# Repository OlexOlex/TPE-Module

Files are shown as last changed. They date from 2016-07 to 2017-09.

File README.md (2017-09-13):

# TPE-Module
**A simple, small, cheap and relatively easy to build module to control 3 PWM driven and 2 binary (on/off) outputs via WIFI and a webinterface** (designed for controlling 3 vibrators and 2 other custom modules, especially in BDSM plays, that's why there is a password protection available)

Runs on any newer ESP8266 module running NodeMCU (the ones with more RAM than the first version, usually featuring 4MB flash)<br/>
The integer version of NodeMCU is reccomended, the floatingpoint accurate version will most probably use too much RAM.

To flash NodeMCU to your module you can use programs like [esptool.py](https://github.com/themadinventor/esptool/blob/master/esptool.py)

To access the NodeMCU filesystem you can use programs like [ESPlorer](http://esp8266.ru/esplorer/)<br/>
You need it to upload the Lua server program, the two configuration files (ESPWIFI.conf and ESPWebserver.conf) and any sequence files. You also need it to test (execute) the Lua server program before renaming it so it gets executed automatically at startup (broken init.lua files might brick your module and force you to re-flash NodeMCU to un-brick it).

In case you change anything in the Lua server program, remember to compress the Lua program for uploading it using [Luasrcdiet](http://esp8266.ru/esplorer/) (otherwise it will most likely bust the modules RAM when executing).

Documentation is not finished by now, I hope this README, the comments, the images and 3D-drawings provided suffice. Browse the project, it consists of only a few files separated into a software and a hardware part.

The Module with an attached vibrating bullet can look like this:

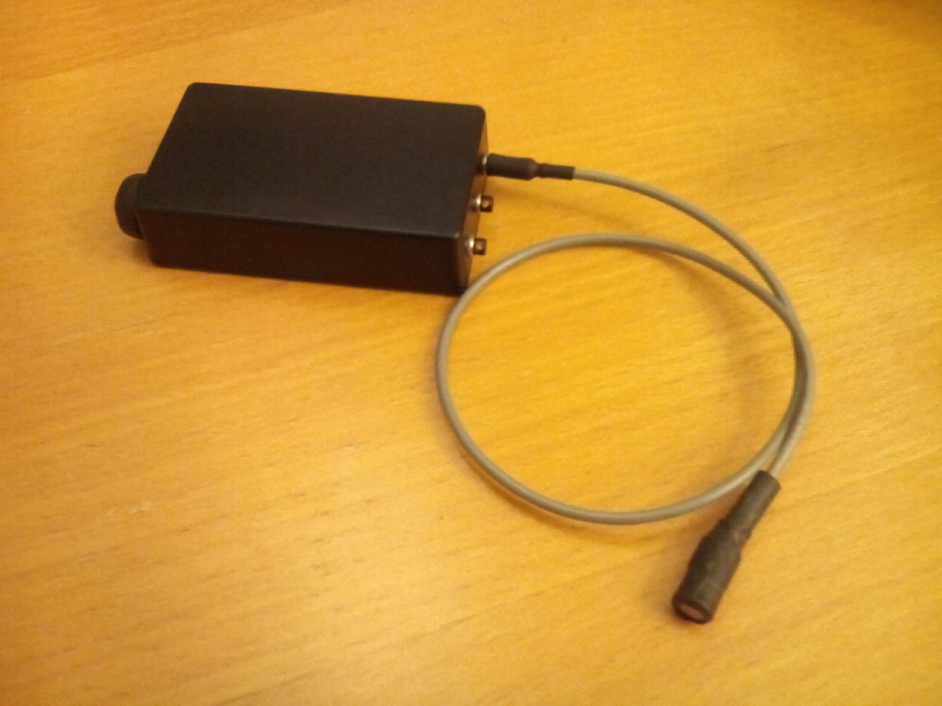
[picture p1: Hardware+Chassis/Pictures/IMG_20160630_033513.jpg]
Module photos


The website can look like this in english, there is an english and a german sample config file available<br/>
Enable or disable any outputs options to be displayed and name (mostly) anything as you wish.<br>
The "Unlock" and "Beep" are just an example, you need to attach a custom module to an output port in order to get any functionality from the two binary outputs. They turn "on" for 20ms  when activated.

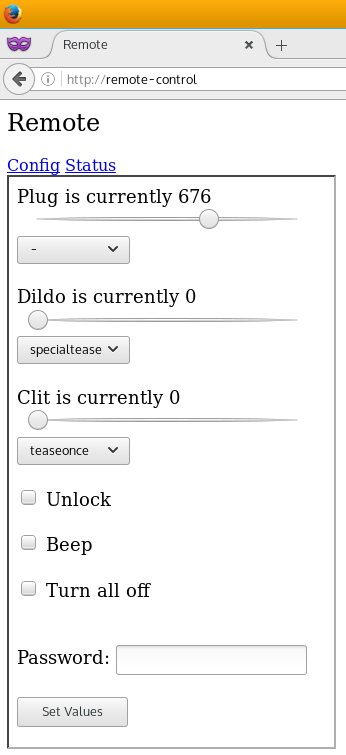
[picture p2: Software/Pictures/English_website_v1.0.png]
Main website screenshot
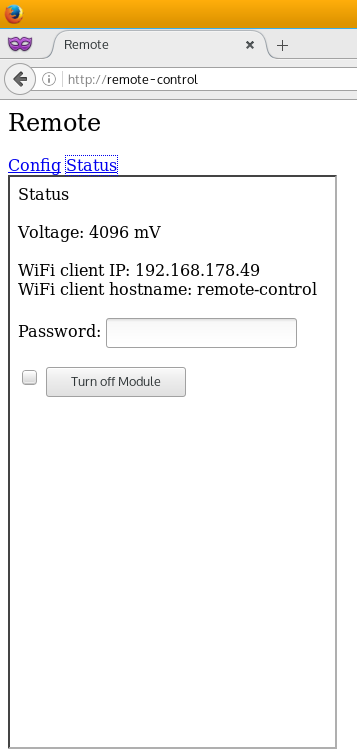
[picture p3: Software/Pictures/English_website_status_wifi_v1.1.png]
Status and turn-off website screenshot
 

## Features:
* Provides a **WIFI-accesspoint** and/or **connects to a (list of) WIFI(s)**, e.g. control it via your home WIFI or outside via the accesspoint
* **Control via web page** in most modern browsers on most systems in the same network (Tested on linux and Android 4.4, only Windows seems to make trouble) - you can also control it with anything that can send HTTP-POST request, e.g. with curl or wget from a linux server, e.g. in a cronjob or bash-/shellscript on a Raspberry Pi
* **No need for a dedicated app**, call the webpage from the private browsing window of your business cell phone and no traces are left, "Is my platform supported?" is answered by "If it has a browser and network access, most probably yes"
* Controls up to **three vibrators** or other things/external modules 0 - 1023 (though the  1-150 are usually useless for vibrators) or runs sequences on the vibrators that are defined in customizable sequence files
* Controls up to **two other external modules** like e-stim, a magnetic (un)lock, a beeper, etc. (gives a short on-signal)
* Nearly everything of the website as well as the WIFI options can be **customized by 2 configuration files** on the integrated primitive filesystem (sadly / luckily not like a USB-stick, you need an easy to use free Java software for access: ESPlorer) 
* Supports many **custom sequences for vibrators** (at least 5 - limited only by NodeMCUs buffer size of 1460 Byte for each output IP packet. This might change in newer versions to even smaller packets) Each sequence is a file in the filesystem with a simple and easy format, available sequence files are autodetected on boot. Name these files as you want the sequences to be shown in the drop down menus
* Runs at least for **13 hours idling** (WIFI acesspoint running, one client connected, simultaniously connected to a WIFI network, a few website requests) with a 3,7V 1200mAh LiPo battery (uses approx. 90mA in idle). Without a client connected to the accesspoint, it runs over 14 hours. It **lasts longer than 30 hours** idling when it does not provide an accesspoint. After that, charge it for 1.5 hours with 1A and you are good to go.
* Turns on on 1 sec button press, you can **turn it off on the website only** - or customize the hardware by using a switch to turn it on and off
* Tick "Turn all off" and then press "Set values" to turn all outputs off (kind of lazy off or "emergency off")
* Configurable **password protection** (enable it by defining a password in the server config file, for disabling password protection make the line defining it a comment)
* **86x51x21,5mm** in size - smaller than a pack of cigaretts. Depending on your skills and the features you want your module to have, you can build it in different cases.
* "Status" page that shows you (roughly!) the current battery voltage and lets you turn off the module (with a voltage divider of 1.5k Ohm to 4.7k Ohm and a multiplication by 4 (as shown/done in the files) below a measured supply voltage of 3000mV the battery will drain quickly (10-15 minutes remain with a 1.5Ah LiPo cell)
* Access it in the local network at its IP, http://[your configured servername here] or its "node-XXXXX" name if the registering of the host name did not work, or http://192.168.4.1 if your device is connected to the modules' accesspoint
* Sockets provide ground, battery voltage and the signal (on = tied to ground, max 0.5A each, max ~3A alltogether until the battery protection turns off power. off = no potential) when the module is turned on, so you can permanently **power external modules/cirquits if needed**, or **run a motor directly** between the signal line and the battery voltage line
* Charge it and access the integrated file system by the integrated usb-serial-adapter with a common **micro USB** cable
* **Noncommercially open source** - details see Licence.txt (tl;dr: No guarantees on anything, use at your own risk, if you think it's good, buy me a beer when we meet or be a good guy in general. In case you want to use it commercially, contact me and we'll find an agreement)
* Material cost: **approximately 14€** for me when buying the stuff in China. Buy it at Aliexpress and then wait for 1.5 months for the items to arrive. (For me two never arrived, I got a refund and got them somewhere else, that is why the ULN2003 module is replaced by a single ULN2003A chip in the photos) A list of the parts is in an OpenOffice spreadsheet in the Hardware+Chassis directory, Ebay and other sources might be good sources as well)
* **Relatively easy to build, most parts are premanufactured ready-to-use-modules**, the connectors are common 3.5mm stereo jacks
* Any simple 3-4V vibrating device with a remote control on a cable can easily be converted to fit this module (and if you solder a socket to the original remote control, you can still use the device with the original remote control )

### Disadvantages:
* Does not (yet?) work with browsers on Windows (tested on Windows 8.1 with Internet Explorer, Google Chrome and Firefox)
* If a browser/system splits an HTTP-POST request to multiple packets (one the HTTP-request, one containing the POST-parameters) it might not work or need a page reload after every request to display the current settings (quickfix for you might be to change a forms request type from POST to GET at two places where the code returns a webpage and change the standard mapping for POST requests to the alternative GET variant)
* It sometimes takes a while until the router knows the device under its configured name, so it might take some time until you can access it at http://[your configured servername here] - once NodeMCU behaviour seems to have changed at that point as well

### Minor "not as perfect as it could be" properties:
* The module runs a Lua interpreter, which was not designed for running a webserver on it, but this project does so. So the current state is close to busting the modules RAM
* "compiling" the script to a .lc file to speed up execution time makes it bigger, thus exceeds the RAM and does not execute at all
* the ESP8266 Module does only support at maximum 4 client devices connected to its WIFI accesspoint
* The voltage reading is rough (only real numbers, no float numbers available for multiplication in the integer version of nodeMCU which is needed for reducing RAM usage)
* The requests are unencrypted HTTP-POST requests - no ssl encryption used
* The Lua-interpreter-firmware (NodeMCU) is still under (heavy?) development, so some functionalities change (for the voltage measuring standard source and the hostname setup I experienced it), and before acessing the filesystem via ESPlorer, you might need to send the =node.heap() command ("Heap"-button) a few times to synchronize the connection
* You could crash the system and force it to reboot by malicously manufactured requests. Requires advanced knowledge.

## Material used for this "full feature" Model:
Detailed information and sample links to the product pages of some online shops are provided in an OpenOffice spreadsheet in the "Hardware" directory. (I got most of it on Aliexpress, Ebay, Amazon and other sources might work as well)
* ESP8266 module ESP-12 (or ESP-12E / ESP-12F) 
* TP4056 micro-USB LiPo charging board with overcurrent and undervoltage protection (not just safe charging but safe discharging as well)
* CP2102 micro-USB to serial adapter (or another 3.3V compatible one)
* ULN2003A chip or module for driving the outputs
* AMS1117 3.3V 800mA voltage regulator (yes, the cheap ones might only reach 2.9V on a close-to-empty battery, but the module runs even with 2.4V, so any cheap one will suffice)
* 3,7V single cell LiPo battery (without any further protection circuit) 62,8mm x 30,3mm x 7,3mm 1200mAh
* ABS plastic box 86x50x21,5mm (or 85x50x21,5mm according to other vendors) or similar
* Button (pus = on, no push = off), a waterproof one might be good
* 5 sockets for 3.5mm stereo audio jacks - use the threaded ones, they are better for glueing to the chassis and can be screwed to the chassis when you drill the outer half of the mounting hole with a larger drill
* Resistors (7x 4,7kOhm, 2x 1,5kOhm)
* 1 Diode (Germanium, silicon may result in a higher voltage drop)
* Cables (a few thicker ones for the main power, thinner ones for the signals)
* 1 N-Channel (MOS)FET transistor (I used an AOD407)
* 1 NPN Transistor (used one of the primitive BC108 ones, but likely any one turning on at 3.3V or lower will work)
* Additionally you might want dust covers for the micro-USB port and the sockets, a "prototyping" pcb (no breadboard) and shrinking tube might be useful as well
* For building a small bullet vibrator a common mobile phone vibration motor and some tube, shrinking tube and a rubber foot/etc for a case + a 2 wire cable

### Tools needed for the module as shown above:
* A soldering iron and some solder wire
* A side cutter or strong scissors for cutting wires, a wire stripper might be handy, too.
* An electric drilling machine (a vertical drilling machine is even more useful)
* A 5mm steel drill for drilling the holes for the 3,5mm sockets to stick through the case, optionally an 8mm steel drill to widen the front of the holes to screw the nuts to the sockets
* A steel or wood drill with the same diameter as the buttons' shaft (or a smaller one and a milling cutter/file for enlargening the hole)
* A 4mm drill and/or milling cutter for drilling the holes for the micro-USB socket (multiple holes next to each other becoming a slot)
* A trianglular or semi-circle file for cleaning the hole for the micro-USB socket
* Waterproof glue and hot glue or similar, to glue the components safely together and to the case (two component resin or silicon might work as well)
* Something to measure and mark where to drill the holes in the case

## How to build one:
* Build the hardware by wiring everything together (use the chassis only for checking the components' later placement)
* Get an image of the NodeMCU firmware, e.g. the copy provided in this project, or get a new one, e.g. at http://nodemcu-build.com/ (!!!*dev branch*!!! many functionalities are not available in the old "stable" branch)
* Flash this image on your ESP-module by turning it on while having a wire between GND ("Minus") and GPIO0 - keep the power button pressed or shortened so it does not turn off again! You can remove the wire from GPIO0 a few moments after tunring the module on. You also might want to have the battery disconnected for this step for security reasons.
* Reboot the module by releasing the power button/shorting, removing the wire to GPIO0 (if you did not allready), and pressing/shorting the power button again (keep presssed/shortened).
* Upload the server Lua script (compressed by Luasrcdiet), the config files and any sequence file you want using e.g. ESPlorer. You might need to request the currently free heap space a few times before the connection is properly synchronized ("Heap"-button in ESPlorer). If you get weird characters but nothing works, close the serial port, change the baud rate (9600 or 115200 most likely) and open it again, then try again reading the free heap space.
* To test it, execute the server script by reloading the file list in ESPlorer ("Reload" button) and click on the file to run it
* If there are no error messages in ESPlorer, your module does not turn off after releasing the button/removing the shorting and there is a WIFI named "remoteWIFI", it works. Try connecting to the WIFI using the password of the WIFI configuration file ("pwd") and test the output sockets (default website passwords: in the english condfg file: mypassword, in the german config file: meinPasswort)
* Change the name of the server Lua script to "init.lua", change your configuration files as you wish and upload them, turn off the module and restart it
* If everything works, assemble the hardware in the chassis to find out and mark where you want to drill the holes (you need a hole for every 3.5mm socket, one for the button, and a slot for the micro-USB socket). Then drill the holes, next assemble and fix everything to the chassis. Don't forget to test if everything works. Additionally you can seal everything with glue and hot glue or whatever you think is useful, so no water can get in the module, or at least hardly any. Be careful though, you do not want to get any glue inside the micro-USB socket!
* Have fun

Questions? Ask me via olexolex at gmx dot de.

## Tested on the following platforms:
Worked on
* Android 4.4 - Android Browser, Firefox
* Android 7.0 - Firefox
* Kubuntu Linux - Firefox, Chromium
* Linux command line - curl

Changing settings did not work on
* Windows 8.1 - Firefox, Google Chrome, Internet Explorer

## Licence

See [Licence.txt](https://github.com/OlexOlex/TPE-Module/blob/master/Licence.txt)

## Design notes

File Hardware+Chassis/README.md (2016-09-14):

# How to build a module (Text not finished, under onstruction!)

## Material you need, in brackets the things used for the full-feature-model:
Detailed information and sample links to the product pages of some online shops are provided in an OpenOffice spreadsheet in the "Hardware" directory. (I got all of it on Aliexpress. Ebay, Amazon and other sources might work as well)
* 1 ESP8266 module, ESP-12 is fitting best at the time (or ESP-12E / ESP-12F)
* 1 battery charging module working as a UPS and a fitting battery (TP4056 micro-USB LiPo charging board with overcurrent and undervoltage protection and a 3,7V single cell LiPo battery without any further protection circuit 62,8mm x 30,3mm x 7,3mm 1200mAh)
* 1 3.3V compatible micro-USB to serial adapter (CP2102 board)
* 1 FET- or transistor array chip (ULN2003A) or module for driving the outputs
* 1 3.3V >300mA voltage regulator (AMS1117) yes, the cheap ones might only reach 2.9V on a close-to-empty battery, but the module runs even with 2.4V, so any cheap one will suffice
* 1 case, which does not shield WIFI (ABS plastic box 86x50x21,5mm or 85x50x21,5mm)
* 1 push button (push = on, no push = off), a waterproof one might be good
* up to 5 sockets for the devices you want to connect if you don't solder their wires directly to the transistor array (5 threaded sockets for 3.5mm stereo audio jacks threaded ones, they are better for glueing to the chassis and can be screwed to the chassis)
* 7 Resistors 4,7kOhm
* 2 Resistors 1,5kOhm
* 1 Diode (Germanium diode!, silicon may result in a too high voltage drop)
* Cables (a few thicker ones for the main power, thinner ones for the signals are good)
* 1 N-Channel (MOS)FET transistor (AOD407)
* 1 NPN Transistor (BC108, likely any one turning on at 2.9V or lower will work)
Optionally:
* dust covers for the micro-USB port and the sockets
* 1 "prototyping" pcb (no breadboard) for the transistor array chip and possibly the power controlling cirquit
* For building a small bullet vibrator the vibrating bullet of a common two-battery-remote controlled vibrating bullet and a 3.5mm stereo audio jack

## Tools needed for the full feature module:
* A soldering iron and some solder wire
* A side cutter or strong scissors for cutting wires, a wire stripper might be handy, too.
* An electric drilling machine (a vertical drilling machine is even more useful)
* A 5mm steel drill for drilling the holes for the 3,5mm sockets to stick through the case, optionally an 8mm steel drill to widen the front of the holes to screw the nuts to the sockets
* A steel or wood drill with the same diameter as the buttons' shaft (or a smaller one and a milling cutter/file for enlargening the hole)
* A 4mm drill and/or milling cutter for drilling the holes for the micro-USB socket (multiple holes next to each other becoming a slot)
* A trianglular or semi-circle file for cleaning the hole for the micro-USB socket
* Waterproof glue and hot glue or similar, to glue the components safely together and to the case (two component resin or silicon might work as well)
* Something to measure and mark where to drill the holes in the case

## Software Tools needed
* A program to flash binaries to a ESP8266 chip (e.g. [esptool.py](https://github.com/themadinventor/esptool/blob/master/esptool.py) )
* A program to comunicate with NodeMCU, upload files, etc (e.g. [ESPlorer](http://esp8266.ru/esplorer/) )

## How to build one:
* Build the hardware by wiring everything together. Use the chassis only for checking the components' later placement, so everything will fit. For wiring, see [the poor wiring diagram for beginners](https://github.com/OlexOlex/TPE-Module/blob/master/Hardware%2BChassis/Module_Wiring.pdf)
* Get an image of the NodeMCU firmware, e.g. [the copy provided](https://github.com/OlexOlex/TPE-Module/tree/master/Software/NodeMCU-image) in this project, or get a new one, e.g. at http://nodemcu-build.com/ (!!!*dev branch*!!! many functionalities are not available in the old "stable" branch)
* Prepare everything for flashing this image to the module, get your flashing program ready (e.g. on linux in the terminal: ./esptool.py --port /dev/ttyUSB0 --baud 115200 write_flash 0x00000000 ./nodemcu-dev-17-modules-2016-04-24-23-38-30-integer.bin )
* Boot your ESP-module to flash mode (so it accepts new firmare images) by turning it on while having a wire between GND ("Minus") and GPIO0 - keep the power button pressed or shortened so it does not turn off again! You can remove the wire from GPIO0 a few moments after tunring the module on. You also might want to have the battery disconnected for this step for safety reasons.
* Run the flash program
* Reboot the module by releasing the power button/shorting, removing the wire to GPIO0 (if you did not allready), and pressing/shorting the power button again (keep presssed/shortened again).
* Upload the server Lua script (the compressed version!), the config files and any sequence files you want. You might need to request the currently free heap space a few times before the connection is properly synchronized ("Heap"-button in ESPlorer). If you get weird characters but nothing works, close the serial port, change the baud rate (9600 or 115200 most likely) and open it again, then try again reading the free heap space multiple times.
* To test it, execute the server script ( reload the file list in ESPlorer ("Reload" button) and click on the file to run it)
* If there are no error messages in ESPlorer, your module does not turn off after releasing the button/removing the shorting and there is a WIFI named "remoteWIFI", it works. Try connecting to the WIFI using the password of the WIFI configuration file ("password") and test the output sockets (default website passwords: in the english condfg file: mypassword, in the german config file: meinPasswort)
* Change the name of the server Lua script to "init.lua", change your configuration files as you wish and upload all changed files. Then turn off the module (using the website) and restart it by pressing the button for approx. one to two seconds.
* If everything works, assemble the hardware in the chassis to find out and mark where you want to drill the holes (you need a hole for every 3.5mm socket, one for the button, and a slot for the micro-USB socket).
* Mark the holes' centers and drill the holes.
* Assemble everything to the chassis.
* Test if everything works.
* Fix everything to the chassis and each other as you like.
* Additionally you can seal everything with glue and hot glue or whatever you think is useful, so no water can get in the module, or at least hardly any. Be careful though, you do not want to get any glue inside the micro-USB socket!
* Have fun!

### Error handling

* If you get no serial connection to the module, make sure it is powered properly and the wiring to the USB-serial adaper is properly done. When powering on, ususally the LED on the ESP board lights up for a short time
* If you brick your module by a corrupt init.lua file or something, just flash NodeMCU to the module and start again with uploading your files to the module.
* If you get "invalid header" every time when flashing (after a successful flash erase), the flash chip of your ESP board might be broken and you need to replace the board (or the chip, if you are good enough).

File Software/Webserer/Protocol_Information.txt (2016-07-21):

If a HTTP request contains no parameters, the appropriate web page is returned
The two subpages are returned only on the specific request "[ulr/IP]/c" (controling the outputs) and "[URL/IP]/s" (voltage reading and turning it off)
Otherwise the main page loading these subpages in a frame is returned.

The POST or GET Parameters (both work, so you can use simple wget commands or similar) are the following:

in all requests:
pwd     The password. If password protection is enabled, this needs to be correct for any other option to be considered

in requests for the /c "Control" page:
pwm1    The value to set the first pwm channel to. Value range: 0-1023 (only relevant if the current sequence seq1 is "-" or set to "-" in the same request. Otherwise this value is ignored)
seq1    The sequence to run for the first pwm channel. Value is one of any known sequences or "-" for no sequence to run but only the static pwm
pwm2    The value to set the second pwm channel to. Value range: 0-1023 (only relevant if the current sequence seq2 is "-" or set to "-" in the same request. Otherwise this value is ignored)
seq1    The sequence to run for the second pwm channel. Value is one of any known sequences or "-" for no sequence to run but only the static pwm
pwm3    The value to set the third pwm channel to. Value range: 0-1023 (only relevant if the current sequence seq3 is "-" or set to "-" in the same request. Otherwise this value is ignored)
seq1    The sequence to run for the third pwm channel. Value is one of any known sequences or "-" for no sequence to run but only the static pwm

pin1    If pin1=1 passed, the appropriate output will turn on for a (very) short time
pin2    If pin2=1 passed, the appropriate output will turn on for a (very) short time

alloff  If alloff=1 is passed, all outputs are turned off, all 

in requests for the /s "Status" page:
off    if off=1 is passed, the module turns itself off

Sample curl commands, e.g. for usage in linux cronjobs or bash-/shellscripts:

# deactivates any running sequence of output 1 and turns it to 300 of 1023 ("seq1=-&pwm1=300")
# activates sequence "tease" for output 3 ("seq3=tease") and
# activates binary output pin 2 for a short period of time ("pin2=1")
# using the password ("pwd=mypassword")
# at the control page of the module ("http://remote-control/c")
curl --data "seq1=-&pwm1=300&seq3=tease&pin2=1&pwd=mypassword" http://remote-control/c

# turns off module ("off=1")
# using the password ("pwd=mypassword")
# at the status page of the module ("http://remote-control/s")
curl --data "off=1&pwd=mypassword" http://remote-control/s

ESPWIFI.conf file format

each line starting with a # character is considered a comment
each other line needs to be of the format
SSID=password
the first SSID=password pair is used for the WiFi accesspoint (enter any ssid/password pair if you don't use the accesspoint)
any further SSID=password line is used for connecting to wifis having this ssid

ESPServer.conf file format

each line starting with a # character is considered a comment
each other line needs to be of the format
parameter=value
see ESPServer.conf sample files to see the needed parameters (English and German, the comments will help you understanding each entry)

Sequence file format:

first line must read the following to identify the file as a sequence file:
pwmsequence

each further line defines the pwm value (0-1023) which will be set for the next period of x miliseconds 
e.g.:
1023, 4000
or
177, 2374
or
0, 100

ast line must read :
repeat, infinite
for infinite repeat of the sequence (until another sequence gets activated), or
repeat, 1
to just run the sequence once (turns off when done or another sequence gets activated)

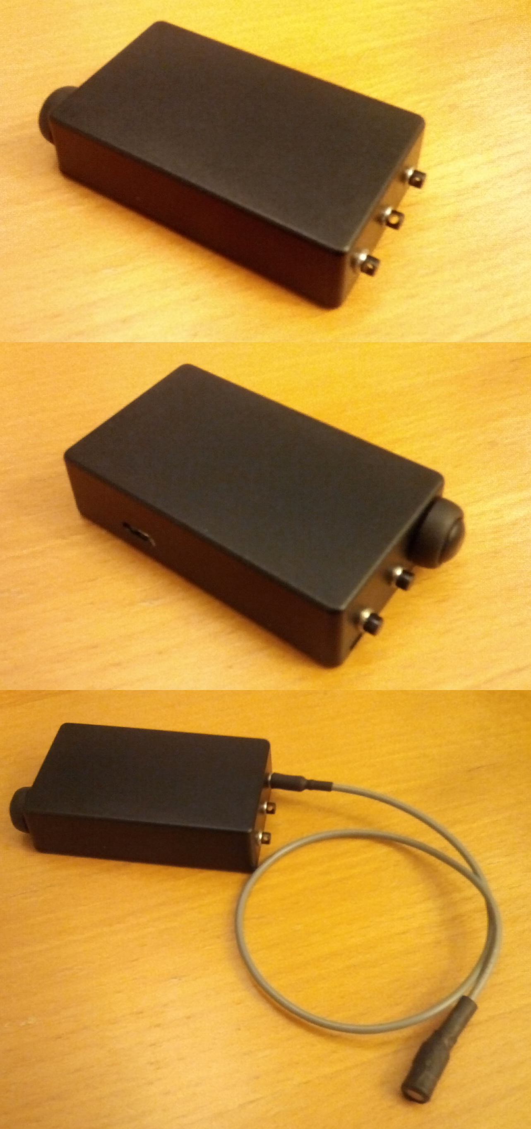
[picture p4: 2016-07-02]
Hardware+Chassis/Pictures/3xBilder.png

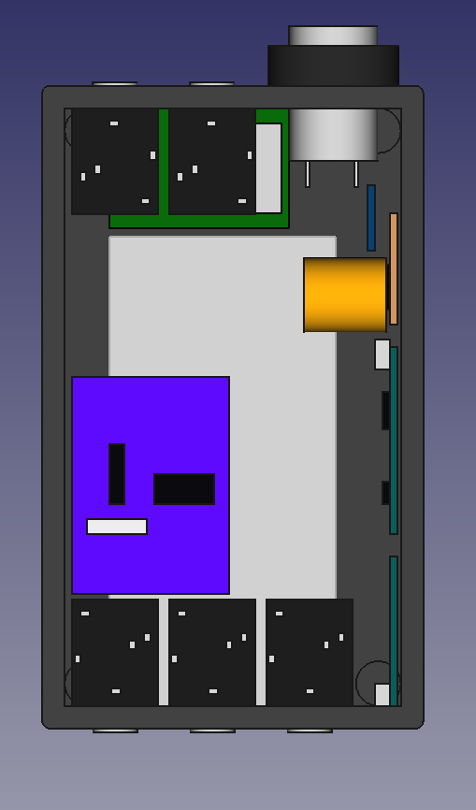
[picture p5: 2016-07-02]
Hardware+Chassis/Part_arrangement-top.png

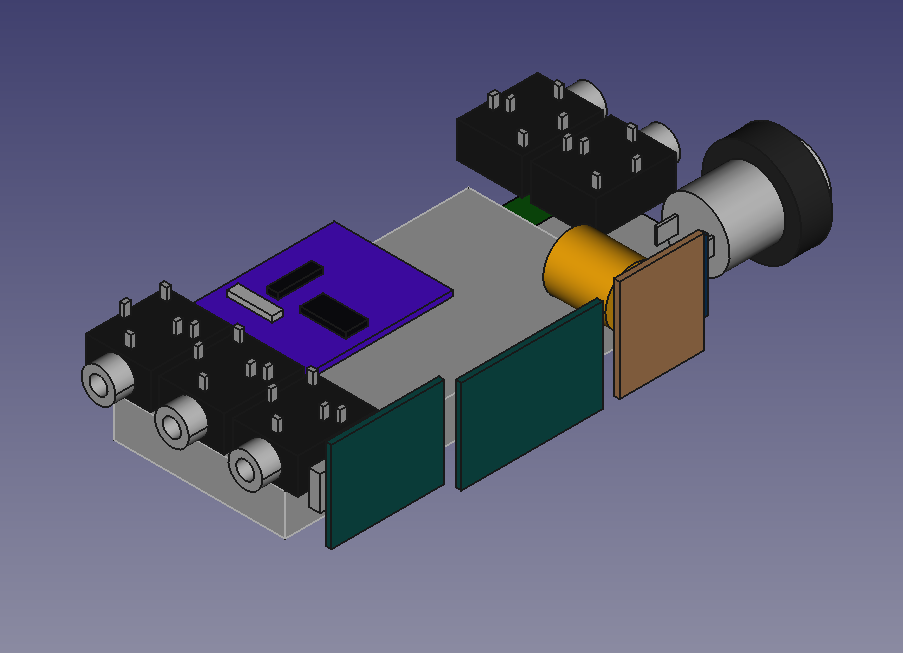
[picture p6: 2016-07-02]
Hardware+Chassis/Part_arrangement.png

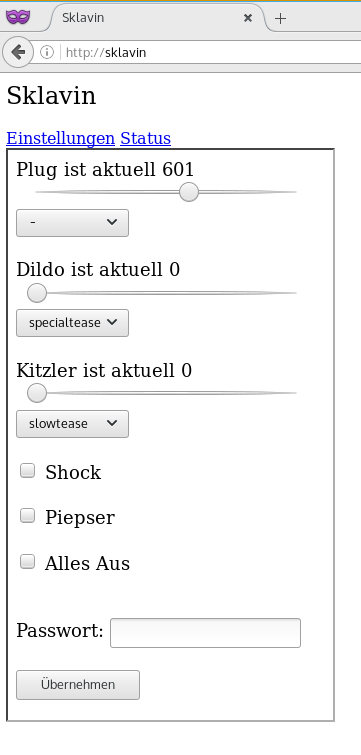
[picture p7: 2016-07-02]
Software/Pictures/German_website_v1.0/Hauptseite_post_Einstellungen.png

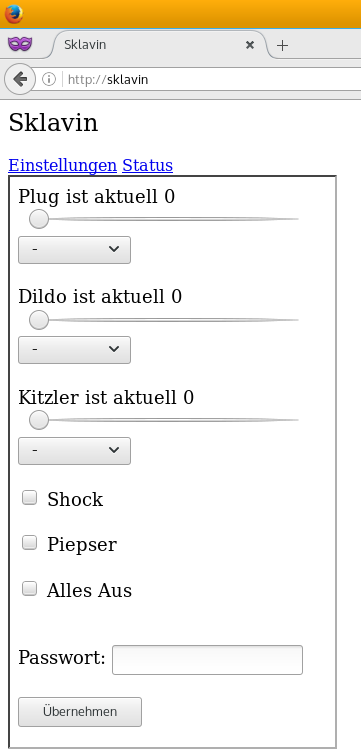
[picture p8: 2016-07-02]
Software/Pictures/German_website_v1.0/Hauptseite.png

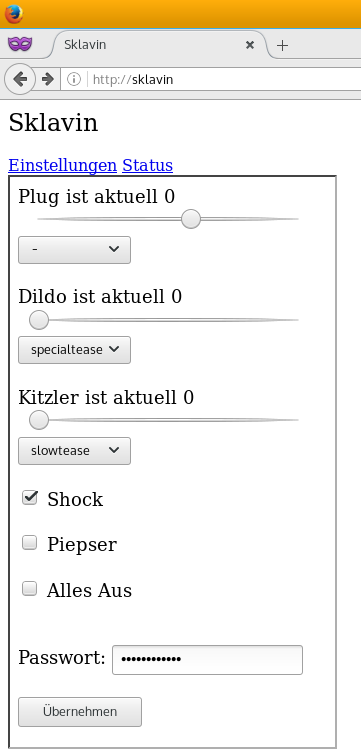
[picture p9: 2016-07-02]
Software/Pictures/German_website_v1.0/Hauptseite_pre_Einstellungen.png

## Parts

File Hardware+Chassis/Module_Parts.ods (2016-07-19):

Part Type/Function | needed amount | Link @ Aliexpress | Price @ link | Amount @ Link | Cost per part | Type | Alternatives
WIFI module ESP-12/12E/12F | 1 | http://de.aliexpress.com/item/Free-Shipping-1pcs-lot-ESP8266-remote-serial-Port-WIFI-wireless-module-through-walls-Wang-ESP-12E/32421572693.html | 1,61 € | 1 | 1,61 € | ESP8266 | any ESP-Module
Voltage regulator 3,3V | 1 | http://de.aliexpress.com/item/Free-Shipping-2pcs-lot-DC-5V-to-3-3V-Step-Down-Power-Supply-Module-AMS1117-3/32499484011.html | 1,00 € | 2 | 0,50 € | AMS1117
Battery management Cirquit | 1 | http://de.aliexpress.com/item/New-1Pcs-lot-5V-1A-Micro-USB-18650-Lithium-Battery-Charging-Board-Charger-Module-Protection-Dual/32657667068.html | 0,35 € | 1 | 0,35 € | TP4056
Driver (some ULN2003) | 1 | http://de.aliexpress.com/item/High-power-ULN2003-Stepper-Motor-Driver-Board-Test-Module-For-Arduino-AVR-SMD/32561202872.html | 0,53 € | 1 | 0,53 € | ULN2003A | ULN2003A Chip + PCB
Programming adapter (USB<->Serial) | 1 | http://de.aliexpress.com/item/CJMCU-CP2102-MICRO-USB-to-UART-TTL-Module-6Pin-Serial-Converter-UART-STC-Replace-FT232-NEW/32579206222.html | 1,33 € | 1 | 1,33 € | CP2102 | IR-Serial connection
Button | 1 | http://de.aliexpress.com/item/Green-12mm-Waterproof-momentary-contact-Push-button-Mini-Round-Switch-250V-1A/32436816553.html | 0,64 € | 1 | 0,64 €
3,5mm-Sockets | 5 | http://de.aliexpress.com/item/Free-Shipping-20PCS-3-5mm-1-8-Female-Audio-Connector-5-Pin-DIP-Stereo-Headphone-Jack/1924121960.html | 2,53 € | 20 | 0,63 €
Single cell LiPo Battery | 1 | http://de.aliexpress.com/item/Bluelans-3-7V-1000MAH-1200mAh-25C-Lipo-Battery-For-RC-Walkera-WKLIPO-5-10-5G4Q3-SYMA/32613443343.html | 3,20 € | 1 | 3,20 € | 3.7V 1200mAh
Chassis | 1 | http://de.aliexpress.com/item/Free-shipping-2-pcs-lot-86-51-22mm-plastic-enclosure-for-electrical-junction-box-abs-plastic/32695626477.html | 3,89 € | 1 | 3,89 €
3,5mm dust cover/cap | 5 | http://de.aliexpress.com/item/100-pcs-Rubber-Anti-Dust-Earphone-Jack-Plug-Stopper-Cap-for-iPhone-Cellphone-0HCC/2019346576.html | 1,49 € | 100 | 0,07 €
Micro-USBdust cover | 1 | http://de.aliexpress.com/item/25-Pcs-Anti-Dust-Soft-Plastic-Dock-Cover-Micro-USB-Port-Ear-Jack/32634689265.html | 0,92 € | 25 | 0,04 €
(MOS)FET für turning power on/off | 1 | http://de.aliexpress.com/item/hot-spot-10pcs-AOD409-SOT252-MOSFET-P-channel-26A-60V-FET-D409/32641092637.html | 1,95 € | 10 | 0,20 € | AOD407
Transistor for driving the FET above | 1 | - | 1,00 € | 15 | 0,07 € | BC108
Resistors | 9 | - | 1,20 € | 100 | 0,11 € | 2x 1,5k, 7x 4,7k
PCB part | 1 | - | 2,00 € | 20 | 0,10 €
Wires | 25 | - | 0,01 € | 1 | 0,25 €
Germanium diode | 1 | - | 0,20 € | 1 | 0,20 €
 |  |  |  | Total: | 13,71 €
Optional
Mini-Vibroegg
3,5mm Plug + cable | 1 | http://de.aliexpress.com/item/1pcs-Hot-3-5mm-Male-to-Female-M-F-Plug-Jack-Headphone-Connector-Audio-Extension-Cable/32610731007.html | 0,56 € | 2 | 0,28 €
Vibrating motor | 1 | http://de.aliexpress.com/item/1pcs-Hot-3-5mm-Male-to-Female-M-F-Plug-Jack-Headphone-Connector-Audio-Extension-Cable/32610731007.html | 1,44 € | 10 | 0,14 €
Tube |  | -
Sealing |  | Rubber anti-slip foot
 |  |  |  | Total: | 0,42 €

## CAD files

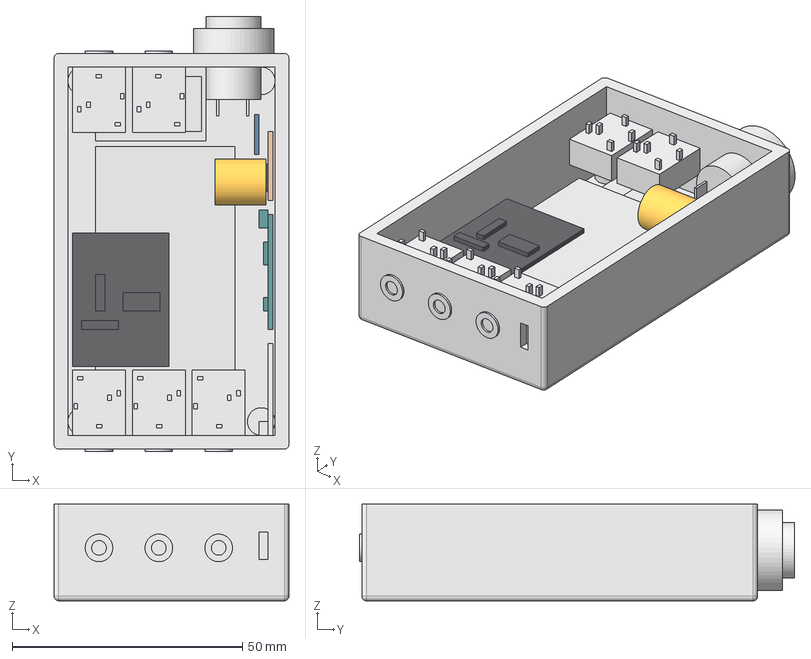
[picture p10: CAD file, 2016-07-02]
Hardware+Chassis/Chassis+part_arrangement.fcstd
51.0 x 94.5 x 21.0 mm
Akku
ESP-12E/F
3,5mm Buchse
3,5mm Buchse001
3,5mm Buchse002
3,5mm Buchse003
3,5mm Buchse004
Taster
Treiberplatine
Ladeplatine
Programmieradapter
Gehäuse
Platine004
HauptFET
Platine005
Zylinder007

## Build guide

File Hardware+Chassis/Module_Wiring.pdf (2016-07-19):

# TPE-Modul Wiring © Olex 2016

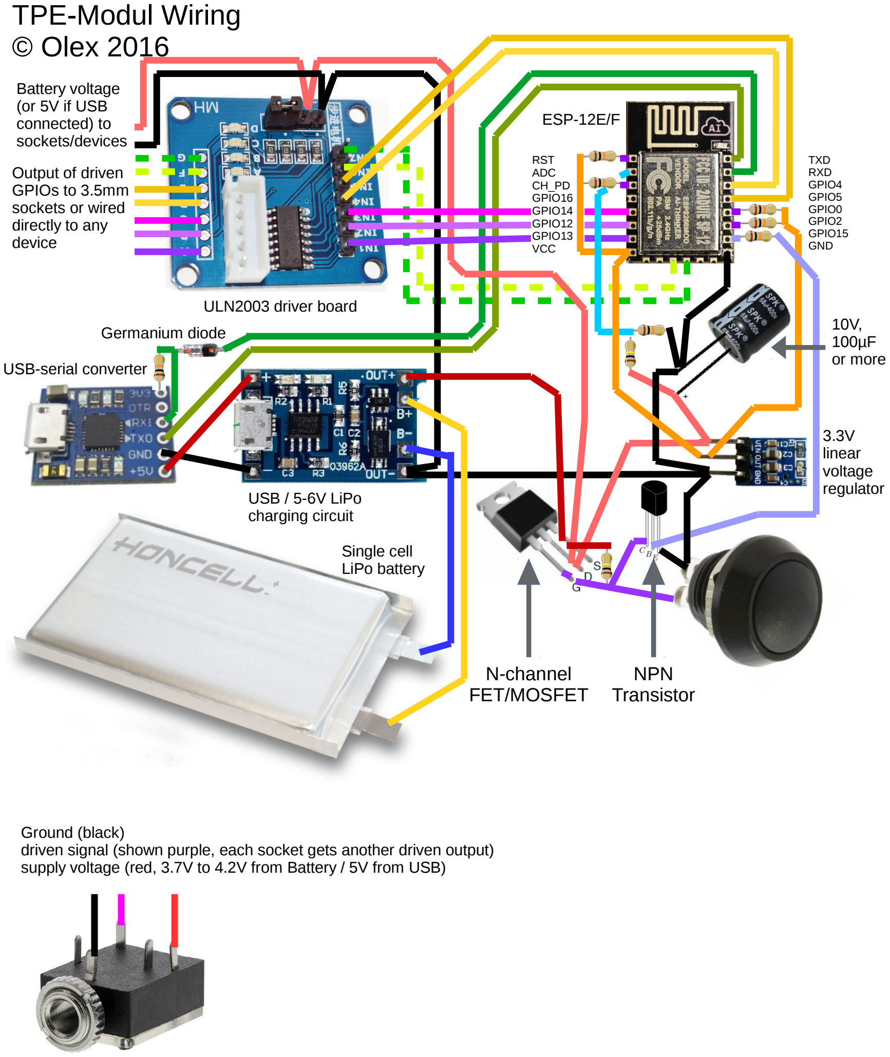
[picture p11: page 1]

TXD
RXD
GPIO4
GPIO5
GPIO0
GPIO2
GPIO15
GND

RST
ADC
CH_PD
GPIO16
GPIO14
GPIO12
GPIO13
VCC

### NPN Transistor

### N-channel FET/MOSFET

Output of driven
GPIOs to 3.5mm
sockets or wired
directly to any
device

Battery voltage
(or 5V if USB
connected) to
sockets/devices

USB-serial converter

USB / 5-6V LiPo
charging circuit

3.3V
linear
voltage
regulator

ESP-12E/F

ULN2003 driver board

Single cell
LiPo battery

Ground (black)
driven signal (shown purple, each socket gets another driven output) supply voltage (red, 3.7V to 4.2V from Battery / 5V from USB)

10V,
100µF
or more

Germanium diode

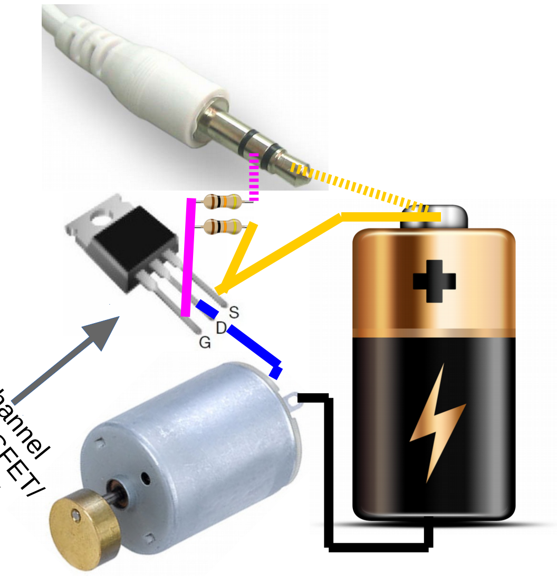
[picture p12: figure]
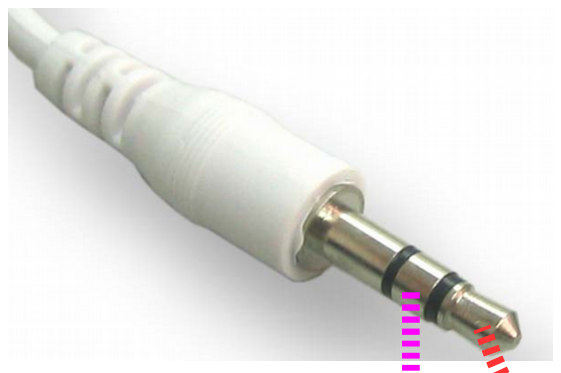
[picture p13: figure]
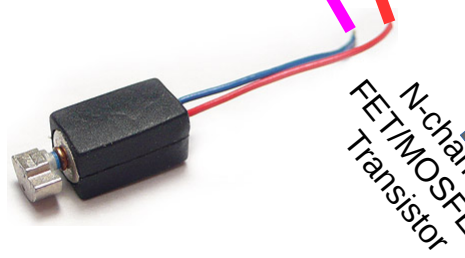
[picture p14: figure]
Transistor

### N-channel

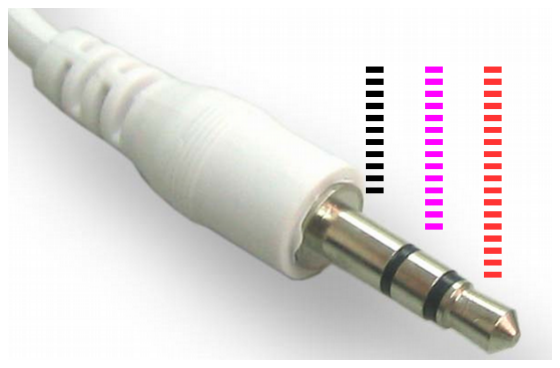
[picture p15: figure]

### FET/MOSFET/

Ground (black)
driven signal (purple)
supply voltage (red, from Battery / 5V from USB)

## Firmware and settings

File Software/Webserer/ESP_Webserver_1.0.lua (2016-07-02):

function blink(pin)
    gpio.write(pin, gpio.HIGH)
    gpio.write(pin, gpio.LOW)
end

function seqOpt(selectedSeq, files)
    local tempbuf = "<option"
    if(selectedSeq == "-") then
        tempbuf = tempbuf.." selected"
    end
    tempbuf = tempbuf..">-</option>"    
    for seq,_ in pairs(files) do
        tempbuf = tempbuf.."<option"
        if (selectedSeq == seq) then
            tempbuf = tempbuf.." selected"
        end
        tempbuf = tempbuf..">"
        tempbuf = tempbuf..seq
        tempbuf = tempbuf.."</option>"
    end
    return tempbuf 
end

-- reads next pwm - timedelta pair, sets the pwm value and the timer
function nextSeqStep(seqname, pwmpin, timerID, currStep)
    local f = file.open(seqname);
    if(f == true) then
        currStep = currStep + 1
        -- read initial line (has no information) plus x steps on. Done in the for loop since lua only compares whether the value is larger in such for loops...
        for i = 0, currStep, 1 do
            line = file.readline();
        end
        file.close()
        if(line == nil) then
            return
        end
        local firstval = ""
        local secval = ""
        for k, v in string.gmatch(line, "(%w+), (%w+)") do
            firstval = k
            secval = string.gsub(v, "\n", "")
        end
        if(firstval ~= nil and secval ~= nil) then
            duty = tonumber(firstval)
            time = tonumber(secval)
        end
        if(duty ~= nil) then
            -- set pwm duty, start timer
            pwm.setduty(pwmpin, duty)
            tmr.alarm(timerID, time, 0, function() 
                nextSeqStep(seqname, pwmpin, timerID, currStep)
            end)
        else
            if(firstval == "repeat") then
                if(time ~= nil) then
                    -- TODO only finite times repeating
                else
                    if(secval == "infinite") then
                        -- start over
                        nextSeqStep(seqname, pwmpin, timerID, 0)
                    else
                        -- end sequence - turn off
                        pwm.setduty(pwmpin, 0)
                    end
                end
            end
        end
    end
end

-- react to successful connection to a wifi network
function onWifiCon()
    local ssid, _, _, _=wifi.sta.getconfig()
    print("connected to wifi "..ssid)
    -- important: works only wiht nodemcu newer than 05.01.2016
    wifi.sta.sethostname(cfg.hostname)
end

-- search for the first known wifi accesspoint and connect to it
function connectToWifi(aplist)
    for ssid,v in pairs(aplist) do
        -- we do know "wifis" (list of ssid/password pairs) from startup
        for knownssid, pwd in pairs(wifis) do
            -- connect to the first known, then return
            if(ssid == knownssid) then
                wifi.sta.config(ssid, pwd)
                print("connecting to wifi "..ssid)
                return
            end
        end
    end
    -- if no known wifi found, try again in 1 second
    tmr.alarm(0, 1000, 0, function() 
                wifi.sta.getap(connectToWifi)
            end)
end

-- raise CPU frequency for startup
node.setcpufreq(node.CPU160MHZ)
gpio.mode(4, gpio.OUTPUT)
gpio.write(4, gpio.HIGH)


collectgarbage()
print("Webserver v1.0")

-- initial field declaration
wificfg = {}
cfg = {}

maxpwmvalue = 1023 -- hardware constant

-- read server config file
if(file.open("ESPWebserver.conf") ~= nil)then
    print("Webserver config opened")
    currline = file.readline()
    while(currline ~= nil) do
        -- if Line is comment, ignore
        if (string.sub(currline,1,1) ~= "#") then
            for k, v in string.gmatch(currline, "([^=]+)=(.+)") do
                -- remove possible line break from v before setting value
                cfg[k] = string.gsub(v, "\n", "")
            end
        end
        currline = file.readline()
    end
    file.close()
else
    print("ERROR opening ESPWebserver.conf")
end

-- important: works only wiht nodemcu newer than 05.01.2016
--wifi.sta.sethostname(cfg.hostname)


-- initialize PWM output
-- pwm.setup(pin, frequency (Hz), duty cycle)
pwm.setup(cfg.pwm1pin,100,0) 
pwm.setup(cfg.pwm2pin,100,0) 
pwm.setup(cfg.pwm3pin,100,0)
pwm.start(cfg.pwm1pin) 
pwm.start(cfg.pwm2pin) 
pwm.start(cfg.pwm3pin)

gpio.mode(cfg.pin1, gpio.OUTPUT)
gpio.mode(cfg.pin2, gpio.OUTPUT)

-- initialize variables
pwm1rate = 0
pwm2rate = 0
pwm3rate = 0
seq1 = "-"
seq2 = "-"
seq3 = "-"
newseq1 = 0
newseq2 = 0
newseq3 = 0

-- register Callbacks to ensure wifi connection
wifi.sta.eventMonReg(wifi.STA_GOTIP, onWifiCon)
wifi.sta.eventMonReg(wifi.STA_WRONGPWD, function() print("Wrong password for wifi network"); wifi.sta.getap(connectToWifi) end)
wifi.sta.eventMonReg(wifi.STA_APNOTFOUND, function() print("Wifi network no longer exists"); wifi.sta.getap(connectToWifi) end)
wifi.sta.eventMonReg(wifi.STA_FAIL, function() print("Failed to connect to wifi network. Unknown reason"); wifi.sta.getap(connectToWifi) end)

-- read wifi config file
wifis = {}
apcfg = {}
if(file.open("ESPWIFI.conf") ~= nil)then
    print("Wifi config opened")
    local currline = file.readline()
    while(currline ~= nil) do
        -- if Line is comment, ignore
        if (string.sub(currline,1,1)~="#") then
            for k, v in string.gmatch(currline, "([^=]+)=(.+)") do
                if(k ~= nil) then
                    -- first wifi config is AP config
                    if(apcfg.ssid == nil) then
                        apcfg.ssid = k
                        -- remove possible line break from v before setting value
                        apcfg.pwd = string.gsub(v, "\n", "")
                        print("read config for accespoint")
                    else
                        wifis[k] = string.gsub(v, "\n", "")
                    end
                end
            end
        end
        currline = file.readline()
    end
    file.close()
end
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

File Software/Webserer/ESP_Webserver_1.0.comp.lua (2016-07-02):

function blink(e)
gpio.write(e,gpio.HIGH)
gpio.write(e,gpio.LOW)
end
function seqOpt(t,a)
local e="<option"
if(t=="-")then
e=e.." selected"
end
e=e..">-</option>"
for a,o in pairs(a)do
e=e.."<option"
if(t==a)then
e=e.." selected"
end
e=e..">"
e=e..a
e=e.."</option>"
end
return e
end
function nextSeqStep(i,o,n,a)
local e=file.open(i);
if(e==true)then
a=a+1
for e=0,a,1 do
line=file.readline();
end
file.close()
if(line==nil)then
return
end
local e=""
local t=""
for a,o in string.gmatch(line,"(%w+), (%w+)")do
e=a
t=string.gsub(o,"\n","")
end
if(e~=nil and t~=nil)then
duty=tonumber(e)
time=tonumber(t)
end
if(duty~=nil)then
pwm.setduty(o,duty)
tmr.alarm(n,time,0,function()
nextSeqStep(i,o,n,a)
end)
else
if(e=="repeat")then
if(time~=nil)then
else
if(t=="infinite")then
nextSeqStep(i,o,n,0)
else
pwm.setduty(o,0)
end
end
end
end
end
end
function onWifiCon()
local e,t,t,t=wifi.sta.getconfig()
print("connected to wifi "..e)
wifi.sta.sethostname(cfg.hostname)
end
function connectToWifi(e)
for e,t in pairs(e)do
for a,t in pairs(wifis)do
if(e==a)then
wifi.sta.config(e,t)
print("connecting to wifi "..e)
return
end
end
end
tmr.alarm(0,1000,0,function()
wifi.sta.getap(connectToWifi)
end)
end
node.setcpufreq(node.CPU160MHZ)
gpio.mode(4,gpio.OUTPUT)
gpio.write(4,gpio.HIGH)
collectgarbage()
print("Webserver v1.0")
wificfg={}
cfg={}
maxpwmvalue=1023
if(file.open("ESPWebserver.conf")~=nil)then
print("Webserver config opened")
currline=file.readline()
while(currline~=nil)do
if(string.sub(currline,1,1)~="#")then
for e,t in string.gmatch(currline,"([^=]+)=(.+)")do
cfg[e]=string.gsub(t,"\n","")
end
end
currline=file.readline()
end
file.close()
else
print("ERROR opening ESPWebserver.conf")
end
pwm.setup(cfg.pwm1pin,100,0)
pwm.setup(cfg.pwm2pin,100,0)
pwm.setup(cfg.pwm3pin,100,0)
pwm.start(cfg.pwm1pin)
pwm.start(cfg.pwm2pin)
pwm.start(cfg.pwm3pin)
gpio.mode(cfg.pin1,gpio.OUTPUT)
gpio.mode(cfg.pin2,gpio.OUTPUT)
pwm1rate=0
pwm2rate=0
pwm3rate=0
seq1="-"
seq2="-"
seq3="-"
newseq1=0
newseq2=0
newseq3=0
wifi.sta.eventMonReg(wifi.STA_GOTIP,onWifiCon)
wifi.sta.eventMonReg(wifi.STA_WRONGPWD,function()print("Wrong password for wifi network");wifi.sta.getap(connectToWifi)end)
wifi.sta.eventMonReg(wifi.STA_APNOTFOUND,function()print("Wifi network no longer exists");wifi.sta.getap(connectToWifi)end)
wifi.sta.eventMonReg(wifi.STA_FAIL,function()print("Failed to connect to wifi network. Unknown reason");wifi.sta.getap(connectToWifi)end)
wifis={}
apcfg={}
if(file.open("ESPWIFI.conf")~=nil)then
print("Wifi config opened")
local e=file.readline()
while(e~=nil)do
if(string.sub(e,1,1)~="#")then
for e,t in string.gmatch(e,"([^=]+)=(.+)")do
if(e~=nil)then
if(apcfg.ssid==nil)then
apcfg.ssid=e
apcfg.pwd=string.gsub(t,"\n","")
print("read config for accespoint")
else
wifis[e]=string.gsub(t,"\n","")
end
end
end
end
e=file.readline()
end
file.close()
end
if(cfg.wifitype=="ap")then
wifi.setmode(wifi.SOFTAP)
if(cfg.APmode==b)then
wifi.setphymode(wifi.PHYMODE_B)
elseif(cfg.APmode==g)then
wifi.setphymode(wifi.PHYMODE_G)
elseif(cfg.APmode==n)then
wifi.setphymode(wifi.PHYMODE_N)
end
wifi.ap.config(apcfg)
print("Accesspoint only mode. SSID: "..apcfg.ssid)
elseif(cfg.wifitype=="cl")then
wifi.setmode(wifi.STATION)
wifi.sta.eventMonStart(200)
wifi.sta.getap(connectToWifi)
print("Client only mode. Connecting to first known wifi.")
elseif(cfg.wifitype=="mix")then
wifi.setmode(wifi.STATIONAP)
wifi.ap.config(apcfg)
print("Mixed mode. Accesspoint SSID: "..apcfg.ssid)
wifi.sta.eventMonStart(200)
wifi.sta.getap(connectToWifi)
else
print("Unknown wifi mode specified")
end
seqfiles=file.list()
for e,t in pairs(seqfiles)do
file.open(e)
firstline=string.gsub(file.readline(),"\n","")
if(firstline~=nil)then
if(firstline=="pwmsequence")then
print("found pwm sequence: "..e)
else
seqfiles[e]=nil
end
else
seqfiles[e]=nil
end
file.close()
end
node.setcpufreq(node.CPU80MHZ)
print("starting server")
srv=net.createServer(net.TCP)
srv:listen(80,function(e)
e:on("receive",function(i,o)
node.setcpufreq(node.CPU160MHZ)
local t={}
local e="<!DOCTYPE html><html>"
local a=string.match(o,"POST (.+) HTTP/.*")
if(a==nil)then
a=string.match(o,"GET (.+) HTTP/.*")
end
local o=string.match(o,".*\n([^\n]+=[^\n]+)")
if(o~=nil)then
for a,e in string.gmatch(o,"([^=&]+)=([^&]+)&*")do
t[a]=e
end
end
if(a==nil or a=="/")then
e=e.."<head><title>"..cfg.servername.."</title><meta name=\"viewport\" content=\"width=300, initial-scale=1, maximum-scale=5\"></head><body><font size=\""..cfg.titlesize.."\">"
e=e..cfg.servername.."</font><br><br><a href=\"c\" target=\"m\">"..cfg.configstr.."</a> <a href=\"s\" target=\"m\">"..cfg.statusstr
e=e.."</a><br><iframe name=\"m\" src=\"c\" height=\""..cfg.frameh.."\" width=\""..cfg.framew.."\"></iframe></body></html>"
elseif(a=="/s")then
if(t.pwd==cfg.pwd and t.off=="1")then
print("Power off")
gpio.write(8,gpio.LOW)
end
e=e.."<body><form action=\"\" method=\"post\">"..cfg.statusstr.."<br><br>"..cfg.vstr.." "..adc.readvdd33().." mV<br><br>"..cfg.pwdstr.." <input type=\"password\" name=\"pwd\"/>"
e=e.."<br><br><input type=\"checkbox\" name=\"off\" value=\"1\"> <input type=\"submit\" value=\""..cfg.turnoffstr.."\" size=\"7\"></body></html>"
elseif(a=="/c")then
if(t.pwd==cfg.pwd)then
if(t.alloff=="1")then
tmr.stop(1)
tmr.stop(2)
tmr.stop(3)
pwm.setduty(cfg.pwm1pin,0)
pwm.setduty(cfg.pwm2pin,0)
pwm.setduty(cfg.pwm3pin,0)
pwm1rate=0
pwm2rate=0
pwm3rate=0
seq1="-"
seq2="-"
seq3="-"
newseq1=0
newseq2=0
newseq3=0
else
if((t.seq1~=nil)and(t.seq1~=seq1))then
seq1=t.seq1
newseq1=1
pwm1rate=0
end
if((t.seq2~=nil)and(t.seq2~=seq2))then
seq2=t.seq2
newseq2=1
pwm2rate=0
end
if((t.seq3~=nil)and(t.seq3~=seq3))then
seq3=t.seq3
newseq3=1
pwm3rate=0
end
if((t.pwm1~=nil)and(seq1=="-")and cfg.pwm1en=="en")then
tmr.stop(1)
pwm1preratio=tonumber(t.pwm1)
if(pwm1preratio~=nil)then
if((pwm1preratio<=maxpwmvalue)and(pwm1preratio>=0))then
pwm1rate=pwm1preratio
pwm.setduty(cfg.pwm1pin,pwm1rate)
end
end
end
if((t.pwm2~=nil)and(seq2=="-")and cfg.pwm2en=="en")then
tmr.stop(2)
pwm2preratio=tonumber(t.pwm2)
if(pwm2preratio~=nil)then
if((pwm2preratio<=maxpwmvalue)and(pwm2preratio>=0))then
pwm2rate=pwm2preratio
pwm.setduty(cfg.pwm2pin,pwm2rate)
end
end
end
if((t.pwm3~=nil)and(seq3=="-")and cfg.pwm3en=="en")then
tmr.stop(3)
pwm3preratio=tonumber(t.pwm3)
if(pwm3preratio~=nil)then
if((pwm3preratio<=maxpwmvalue)and(pwm3preratio>=0))then
pwm3rate=pwm3preratio
pwm.setduty(cfg.pwm3pin,pwm3rate)
end
end
end
end
else
print("wrong password")
end
e=e.."<body><form action=\"\" method=\"post\" ><font size=\""..cfg.textsize.."\" face=\"Verdana\">"
if(cfg.pwm1en=="en")then
e=e..cfg.pwm1..cfg.iscurrstr..pwm1rate.."<br> <input type=\"range\" name=\"pwm1\" value=\""..pwm1rate
e=e.."\"  min=\"0\" max=\"1023\" class=fw><br><select name=\"seq1\">"..seqOpt(seq1,seqfiles).."</select><br><br>"
end
if(cfg.pwm2en=="en")then
e=e..cfg.pwm2..cfg.iscurrstr..pwm2rate.."<br> <input type=\"range\" name=\"pwm2\" value=\""..pwm2rate
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

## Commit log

2016-07-02 Initial commit, beware of potential errors with the newest version of NodeMCU
    [Chassis+part_arrangement.fcstd, Module_Parts.ods]
2016-07-04 Updated comments and the ADC usage for displaying the current supply voltage (compressed version not yet updated to multiply measured voltage by 4.1
2016-07-05 fixed voltage reading on status page (still works only with NodeMCU versions that default to read the voltage on ADC-pin)
    [ESP_Webserver.comp.lua, ESP_Webserver.lua]
2016-07-19 Added more functionality to the status page
    [Module_Parts.ods]
2016-07-19 Fixed Bug when module is in no WiFi but tries to get the station IP
    [ESP_Webserver.comp.lua, ESP_Webserver.lua]
2016-07-20 Minor changes in comments, potential bugfixes, added screenshot showing station IP and hostname of the module
    [ESP_Webserver.comp.lua, ESP_Webserver.lua]
